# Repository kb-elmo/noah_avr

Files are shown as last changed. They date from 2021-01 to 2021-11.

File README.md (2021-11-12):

# Noah AVR

[][cc-by-nc-sa]
<a href="https://ko-fi.com/kb_elmo">kofibadge</a>

## This project is completed and will not get updated anymore.

### Atmega32u4 based drop-in replacement PCB for the Matrix Noah keyboard



---

[LCSC BOM](noah.csv)

[JLC CPL](noah-bottom-pos.csv)

[JST connectors for USB and RGB](https://www.digikey.de/product-detail/en/jst-sales-america-inc/SM04B-SRSS-TB-LF-SN/455-1804-1-ND/926875)

[SMD standoffs for daughterboard](https://www.digikey.de/en/products/detail/w%C3%BCrth-elektronik/9774030243R/5320628)

---




This work is licensed under a
[Creative Commons Attribution-NonCommercial-ShareAlike 4.0 International License][cc-by-nc-sa].

[][cc-by-nc-sa]

[cc-by-nc-sa]: http://creativecommons.org/licenses/by-nc-sa/4.0/
[cc-by-nc-sa-image]: https://licensebuttons.net/l/by-nc-sa/4.0/88x31.png
[cc-by-nc-sa-shield]: https://img.shields.io/badge/License-CC%20BY--NC--SA%204.0-lightgrey.svg

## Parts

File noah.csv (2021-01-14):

Comment | Designator | Footprint | LCSC
10uF | C1 | Capacitor_SMD:C_0805_2012Metric | C91245
0.1uF | C2,C3,C4,C5 | Capacitor_SMD:C_0805_2012Metric | C49678
1uF | C7 | Capacitor_SMD:C_0805_2012Metric | C28323
22pF | C8,C9 | Capacitor_SMD:C_0805_2012Metric | C1804
D_Small | D1,D2,D3,D4,D5,D6,D7,D8,D9,D10,D11,D12,D13,D14,D15,D17,D18,D19,D20,D21,D22,D23,D24,D25,D26,D27,D28,D29,D30,D32,D33,D35,D36 | custom_parts:D_SOT-23_ANK | C68978
D_Small | D16,D31,D34 | Diode_SMD:D_SOD-123 | C81598
Polyfuse_Small | F1 | Fuse:Fuse_1206_3216Metric | C163133
MountingHole | H1,H2,H3,H4 | MountingHole:MountingHole_3mm_Pad_Via
MX-NoLED | MX1 | MX_Only:MXOnly-2U-NoLED
MX-NoLED | MX19,MX32,MX66,MX68,MX70 | MX_Only:MXOnly-1.5U-NoLED
MX-NoLED | MX2,MX3,MX4,MX5,MX6,MX7,MX8,MX9,MX10,MX11,MX12,MX13,MX14,MX15,MX16,MX17,MX18,MX20,MX21,MX22,MX23,MX24,MX25,MX26,MX27,MX28,MX29,MX30,MX31,MX33,MX37,MX38,MX39,MX40,MX41,MX42,MX43,MX44,MX45,MX46,MX47,MX49,MX52,MX53,MX54,MX55,MX56,MX57,MX58,MX59,MX60,MX61,MX62,MX64,MX65,MX67,MX77,MX78,MX79 | MX_Only:MXOnly-1U-NoLED
MX-LED | MX34 | custom_parts:MXOnly-1.25U-flipped-LED
MX-NoLED | MX35 | custom_parts:MXOnly-ISO-ReversedStabilizers-NoLED
MX-LED | MX36 | MX_Only:MXOnly-1.75U
MX-NoLED | MX48 | MX_Only:MXOnly-2.25U-ReversedStabilizers-NoLED
MX-NoLED | MX51 | MX_Only:MXOnly-2.25U-NoLED
MX-NoLED | MX63 | MX_Only:MXOnly-1.75U-NoLED
MX-NoLED | MX69 | MX_Only:MXOnly-7U-ReversedStabilizers-NoLED
MX-NoLED | MX50,MX71,MX72,MX73,MX75,MX76 | MX_Only:MXOnly-1.25U-NoLED
MX-NoLED | MX74 | MX_Only:MXOnly-6.25U-ReversedStabilizers-NoLED
22 | R1,R2 | Resistor_SMD:R_0805_2012Metric | C17561
10k | R3,R5 | Resistor_SMD:R_0805_2012Metric | C17414
1k | R4 | Resistor_SMD:R_0805_2012Metric | C17513
SW_Push | RESET | random-keyboard-parts:SKQG-1155865 | C318884
ATmega32U4-AU | U1 | Package_QFP:TQFP-44_10x10mm_P0.8mm | C44854
SRV05-4 | U2 | Package_TO_SOT_SMD:SOT-23-6 | C85364
Conn_01x04 | USB1,RGB1 | Connector_JST:JST_SH_SM04B-SRSS-TB_1x04-1MP_P1.00mm_Horizontal
Crystal_GND24_Small | XTAL1 | Crystal:Crystal_SMD_3225-4Pin_3.2x2.5mm | C13738

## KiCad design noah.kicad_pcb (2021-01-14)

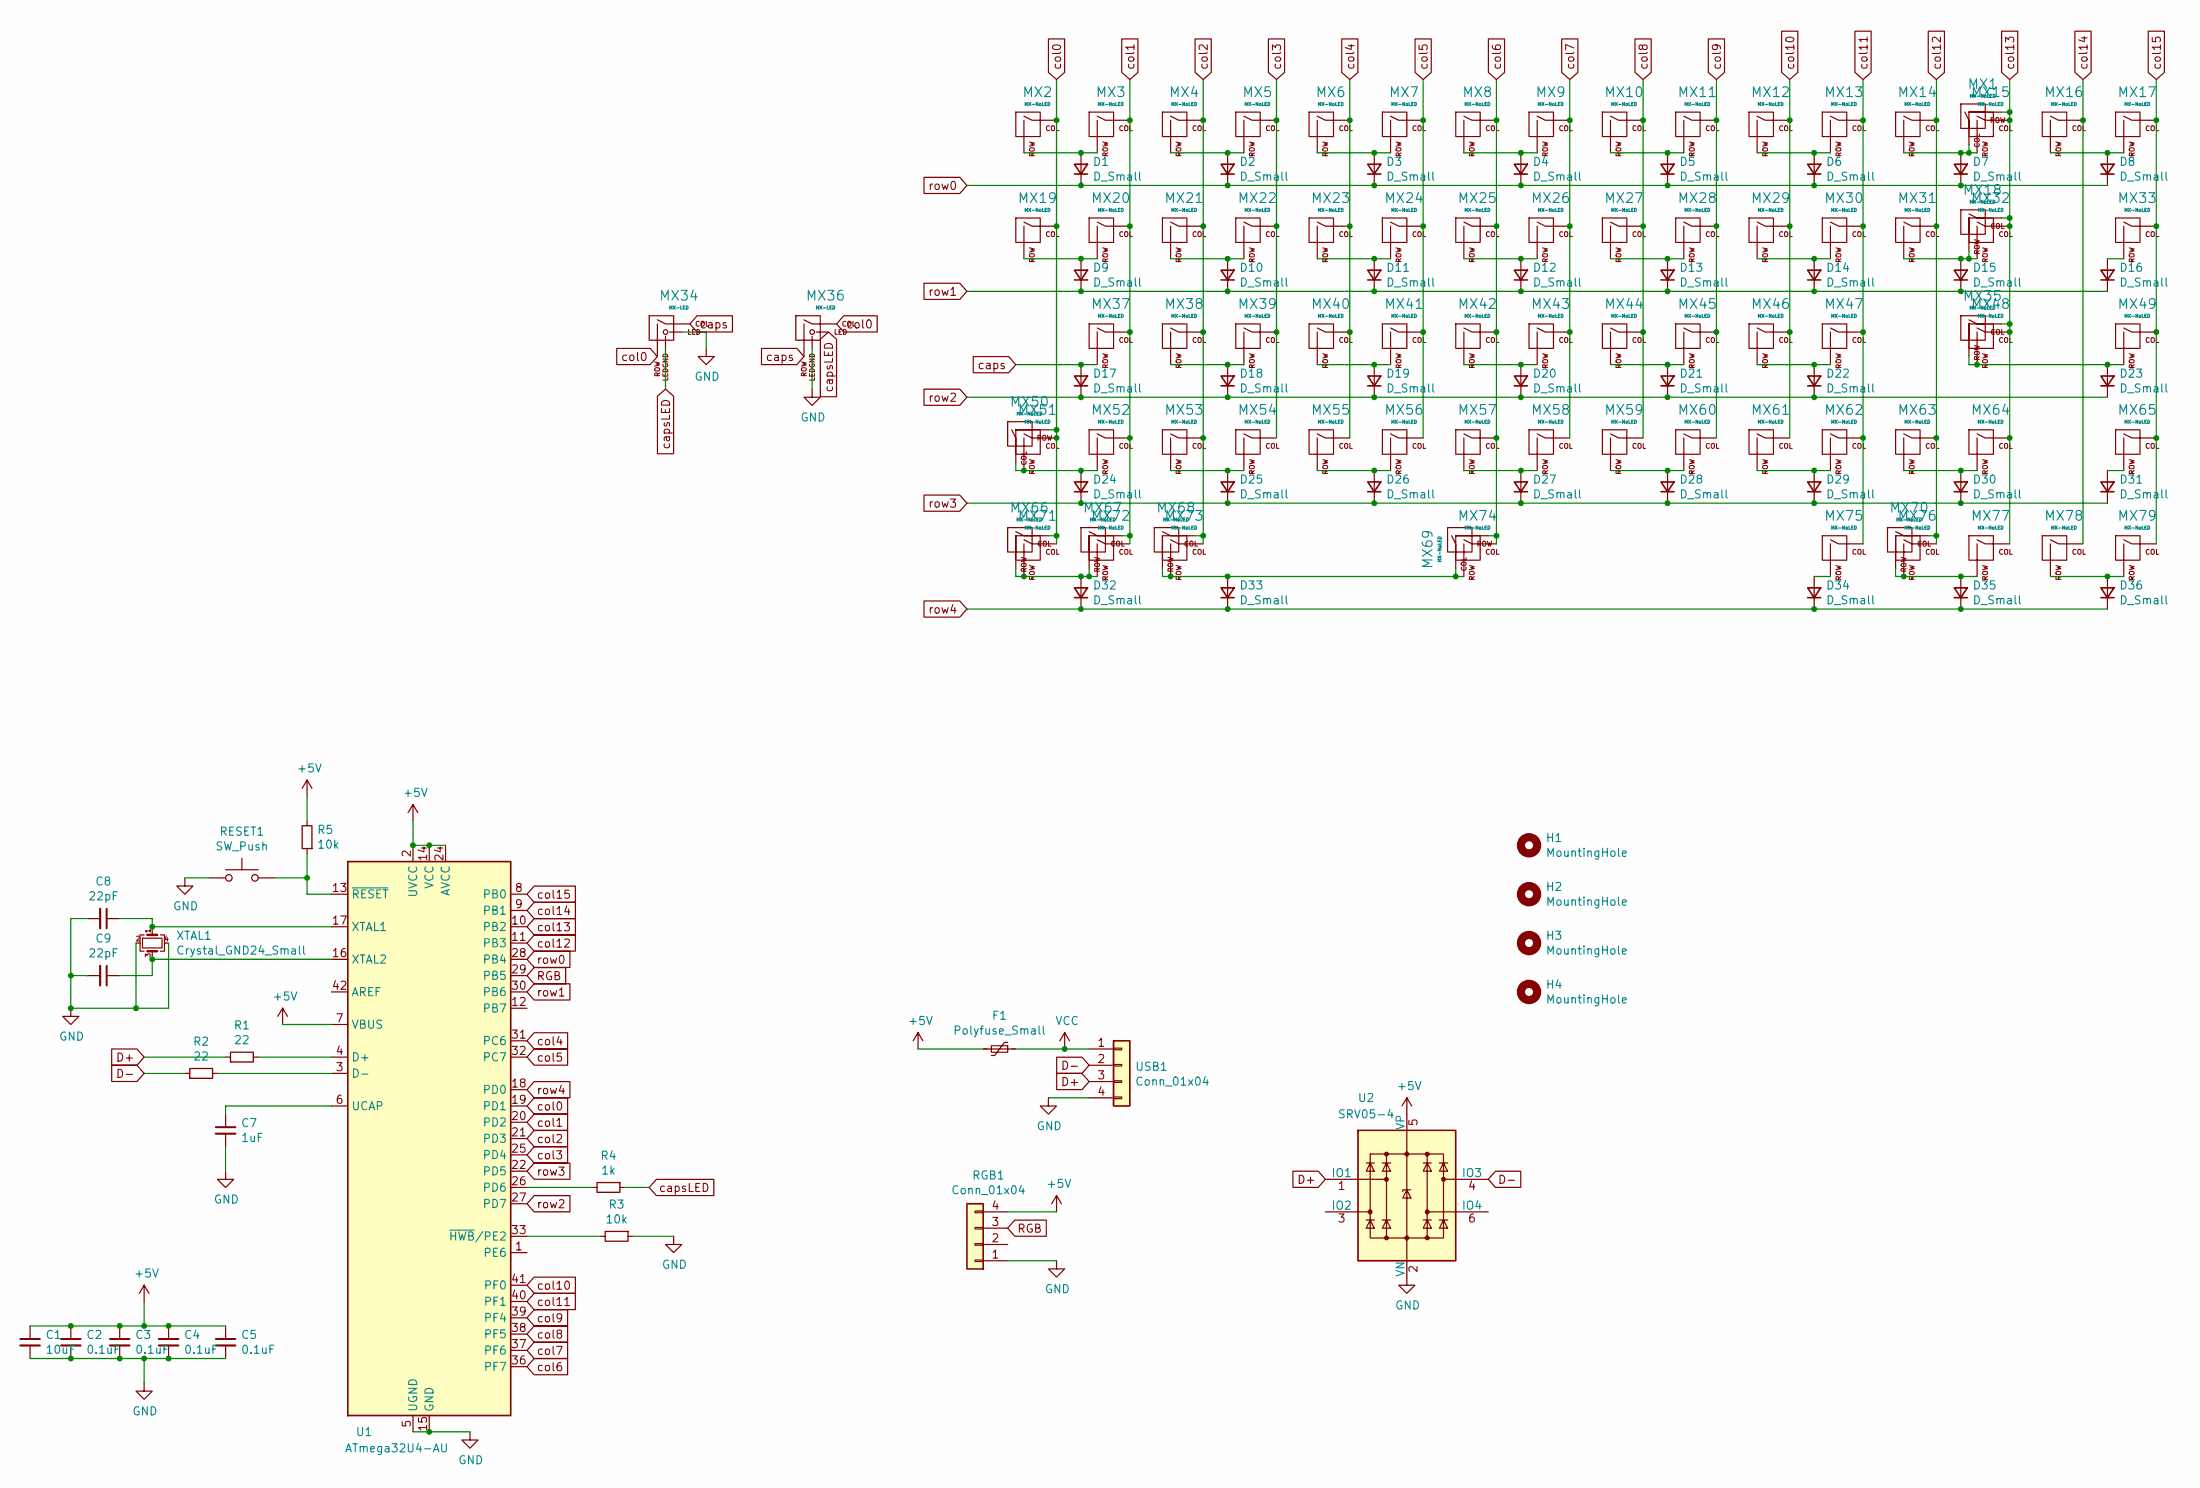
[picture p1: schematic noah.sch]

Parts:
C1: 10uF; C_0805_2012Metric; LCSC C91245
C2, C3, C4, C5: 0.1uF; C_0805_2012Metric; LCSC C49678
C7: 1uF; C_0805_2012Metric; LCSC C28323
C8, C9: 22pF; C_0805_2012Metric; LCSC C1804
D1, D2, D3, D4, D5, D6, D7, D8, D9, D10, D11, D12, D13, D14, D15, D17, D18, D19, D20, D21, D22, D23, D24, D25, D26, D27, D28, D29, D30, D32, D33, D35, D36: D_Small; D_SOT-23_ANK; LCSC C68978
D16, D31, D34: D_Small; D_SOD-123; LCSC C81598
F1: Polyfuse_Small; Fuse_1206_3216Metric; LCSC C163133
H1, H2, H3, H4: MountingHole; MountingHole_3mm_Pad_Via
MX1: MX-NoLED; MXOnly-2U-NoLED
MX2, MX3, MX4, MX5, MX6, MX7, MX8, MX9, MX10, MX11, MX12, MX13, MX14, MX15, MX16, MX17, MX18, MX20, MX21, MX22, MX23, MX24, MX25, MX26, MX27, MX28, MX29, MX30, MX31, MX33, MX37, MX38, MX39, MX40, MX41, MX42, MX43, MX44, MX45, MX46, MX47, MX49, MX52, MX53, MX54, MX55, MX56, MX57, MX58, MX59, MX60, MX61, MX62, MX64, MX65, MX67, MX77, MX78, MX79: MX-NoLED; MXOnly-1U-NoLED
MX19, MX32, MX66, MX68, MX70: MX-NoLED; MXOnly-1.5U-NoLED
MX34: MX-LED; MXOnly-1.25U-flipped-LED
MX35: MX-NoLED; MXOnly-ISO-ReversedStabilizers-NoLED
MX36: MX-LED; MXOnly-1.75U
MX48: MX-NoLED; MXOnly-2.25U-ReversedStabilizers-NoLED
MX50, MX71, MX72, MX73, MX75, MX76: MX-NoLED; MXOnly-1.25U-NoLED
MX51: MX-NoLED; MXOnly-2.25U-NoLED
MX63: MX-NoLED; MXOnly-1.75U-NoLED
MX69: MX-NoLED; MXOnly-7U-ReversedStabilizers-NoLED
MX74: MX-NoLED; MXOnly-6.25U-ReversedStabilizers-NoLED
R1, R2: 22; R_0805_2012Metric; LCSC C17561
R3, R5: 10k; R_0805_2012Metric; LCSC C17414
R4: 1k; R_0805_2012Metric; LCSC C17513
RESET1: SW_Push; SKQG-1155865; LCSC C318884
RGB1: Conn_01x04; JST_SH_SM04B-SRSS-TB_1x04-1MP_P1.00mm_Horizontal
U1: ATmega32U4-AU; TQFP-44_10x10mm_P0.8mm; LCSC C44854
U2: SRV05-4; SOT-23-6; LCSC C85364
USB1: Conn_01x04; JST_SH_SM04B-SRSS-TB_1x04-1MP_P1.00mm_Horizontal
XTAL1: Crystal_GND24_Small; Crystal_SMD_3225-4Pin_3.2x2.5mm; LCSC C13738

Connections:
+5V: C1.1, C2.1, C3.1, C4.1, C5.1, F1.2, R5.2, RGB1.4, U1.2 (UVCC), U1.7 (VBUS), U1.14 (VCC), U1.24 (AVCC), U1.34 (VCC), U1.44 (AVCC), U2.5 (VP)
D+: R1.1, U2.1 (IO1), USB1.3
D-: R2.1, U2.4 (IO3), USB1.2
GND: C1.2, C2.2, C3.2, C4.2, C5.2, C7.2, C8.2, C9.2, MX34.3 (LED), MX36.4 (LEDGND), R3.1, RESET1.1, RGB1.1, U1.5 (UGND), U1.15 (GND), U1.23 (GND), U1.35 (GND), U1.43 (GND), U2.2 (VN), USB1.4, XTAL1.2, XTAL1.4; also elsewhere on the board
unnamed: C7.1, U1.6 (UCAP)
unnamed: C8.1, U1.17 (XTAL1), XTAL1.1
unnamed: C9.1, U1.16 (XTAL2), XTAL1.3
unnamed: D1.2 (A), MX2.2 (ROW), MX3.2 (ROW)
unnamed: D2.2 (A), MX4.2 (ROW), MX5.2 (ROW)
unnamed: D3.2 (A), MX6.2 (ROW), MX7.2 (ROW)
unnamed: D4.2 (A), MX8.2 (ROW), MX9.2 (ROW)
unnamed: D5.2 (A), MX10.2 (ROW), MX11.2 (ROW)
unnamed: D6.2 (A), MX12.2 (ROW), MX13.2 (ROW)
unnamed: D7.2 (A), MX1.1 (COL), MX14.2 (ROW), MX15.2 (ROW)
unnamed: D8.2 (A), MX16.2 (ROW), MX17.2 (ROW)
unnamed: D9.2 (A), MX19.2 (ROW), MX20.2 (ROW)
unnamed: D10.2 (A), MX21.2 (ROW), MX22.2 (ROW)
unnamed: D11.2 (A), MX23.2 (ROW), MX24.2 (ROW)
unnamed: D12.2 (A), MX25.2 (ROW), MX26.2 (ROW)
unnamed: D13.2 (A), MX27.2 (ROW), MX28.2 (ROW)
unnamed: D14.2 (A), MX29.2 (ROW), MX30.2 (ROW)
unnamed: D15.2 (A), MX18.2 (ROW), MX31.2 (ROW), MX32.2 (ROW)
unnamed: D16.2 (A), MX33.2 (ROW)
unnamed: D18.2 (A), MX38.2 (ROW), MX39.2 (ROW)
unnamed: D19.2 (A), MX40.2 (ROW), MX41.2 (ROW)
unnamed: D20.2 (A), MX42.2 (ROW), MX43.2 (ROW)
unnamed: D21.2 (A), MX44.2 (ROW), MX45.2 (ROW)
unnamed: D22.2 (A), MX46.2 (ROW), MX47.2 (ROW)
unnamed: D23.2 (A), MX35.2 (ROW), MX48.2 (ROW), MX49.2 (ROW)
unnamed: D24.2 (A), MX50.1 (COL), MX51.2 (ROW), MX52.2 (ROW)
unnamed: D25.2 (A), MX53.2 (ROW), MX54.2 (ROW)
unnamed: D26.2 (A), MX55.2 (ROW), MX56.2 (ROW)
unnamed: D27.2 (A), MX57.2 (ROW), MX58.2 (ROW)
unnamed: D28.2 (A), MX59.2 (ROW), MX60.2 (ROW)
unnamed: D29.2 (A), MX61.2 (ROW), MX62.2 (ROW)
unnamed: D30.2 (A), MX63.2 (ROW), MX64.2 (ROW)
unnamed: D31.2 (A), MX65.2 (ROW)
unnamed: D32.2 (A), MX66.2 (ROW), MX67.2 (ROW), MX71.2 (ROW), MX72.2 (ROW)
unnamed: D33.2 (A), MX68.2 (ROW), MX69.1 (COL), MX73.2 (ROW), MX74.2 (ROW)
unnamed: D34.2 (A), MX75.2 (ROW)
unnamed: D35.2 (A), MX70.2 (ROW), MX76.2 (ROW), MX77.2 (ROW)
unnamed: D36.2 (A), MX78.2 (ROW), MX79.2 (ROW)
unnamed: R1.2, U1.4 (D+)
unnamed: R2.2, U1.3 (D-)
unnamed: R3.2, U1.33 (~HWB~/PE2)
unnamed: R4.2, U1.26 (PD6)
unnamed 46: R5.1, RESET1.2, U1.13 (~RESET); also elsewhere on the board
RGB: RGB1.3, U1.29 (PB5)
VCC: F1.1, USB1.1
caps: D17.2 (A), MX34.1 (COL), MX36.2 (ROW), MX37.2 (ROW)
capsLED: MX34.4 (LEDGND), MX36.3 (LED), R4.1
col0: MX2.1 (COL), MX19.1 (COL), MX34.2 (ROW), MX36.1 (COL), MX50.2 (ROW), MX51.1 (COL), MX66.1 (COL), MX71.1 (COL), U1.19 (PD1)
col1: MX3.1 (COL), MX20.1 (COL), MX37.1 (COL), MX52.1 (COL), MX67.1 (COL), MX72.1 (COL), U1.20 (PD2)
col2: MX4.1 (COL), MX21.1 (COL), MX38.1 (COL), MX53.1 (COL), MX68.1 (COL), MX73.1 (COL), U1.21 (PD3)
col3: MX5.1 (COL), MX22.1 (COL), MX39.1 (COL), MX54.1 (COL), U1.25 (PD4)
col4: MX6.1 (COL), MX23.1 (COL), MX40.1 (COL), MX55.1 (COL), U1.31 (PC6)
col5: MX7.1 (COL), MX24.1 (COL), MX41.1 (COL), MX56.1 (COL), U1.32 (PC7)
col6: MX8.1 (COL), MX25.1 (COL), MX42.1 (COL), MX57.1 (COL), MX69.2 (ROW), MX74.1 (COL), U1.36 (PF7)
col7: MX9.1 (COL), MX26.1 (COL), MX43.1 (COL), MX58.1 (COL), U1.37 (PF6)
col8: MX10.1 (COL), MX27.1 (COL), MX44.1 (COL), MX59.1 (COL), U1.38 (PF5)
col9: MX11.1 (COL), MX28.1 (COL), MX45.1 (COL), MX60.1 (COL), U1.39 (PF4)
col10: MX12.1 (COL), MX29.1 (COL), MX46.1 (COL), MX61.1 (COL), U1.41 (PF0)
col11: MX13.1 (COL), MX30.1 (COL), MX47.1 (COL), MX62.1 (COL), MX75.1 (COL), U1.40 (PF1)
col12: MX14.1 (COL), MX31.1 (COL), MX63.1 (COL), MX70.1 (COL), MX76.1 (COL), U1.11 (PB3)
col13: MX1.2 (ROW), MX15.1 (COL), MX18.1 (COL), MX32.1 (COL), MX35.1 (COL), MX48.1 (COL), MX64.1 (COL), MX77.1 (COL), U1.10 (PB2)
col14: MX16.1 (COL), MX78.1 (COL), U1.9 (PB1)
col15: MX17.1 (COL), MX33.1 (COL), MX49.1 (COL), MX65.1 (COL), MX79.1 (COL), U1.8 (PB0)
row0: D1.1 (K), D2.1 (K), D3.1 (K), D4.1 (K), D5.1 (K), D6.1 (K), D7.1 (K), D8.1 (K), U1.28 (PB4)
row1: D9.1 (K), D10.1 (K), D11.1 (K), D12.1 (K), D13.1 (K), D14.1 (K), D15.1 (K), D16.1 (K), U1.30 (PB6)
row2: D17.1 (K), D18.1 (K), D19.1 (K), D20.1 (K), D21.1 (K), D22.1 (K), D23.1 (K), U1.27 (PD7)
row3: D24.1 (K), D25.1 (K), D26.1 (K), D27.1 (K), D28.1 (K), D29.1 (K), D30.1 (K), D31.1 (K), U1.22 (PD5)
row4: D32.1 (K), D33.1 (K), D34.1 (K), D35.1 (K), D36.1 (K), U1.18 (PD0)

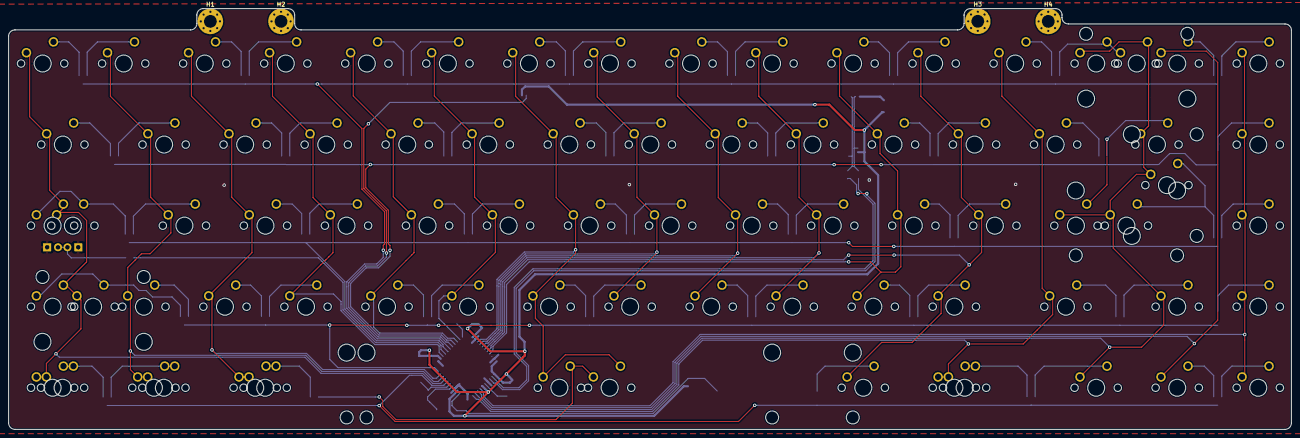
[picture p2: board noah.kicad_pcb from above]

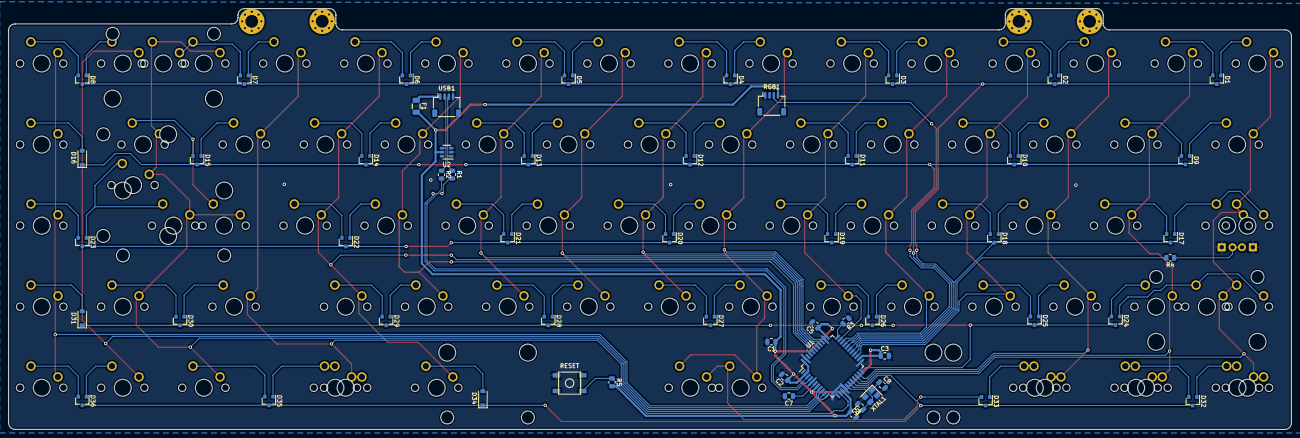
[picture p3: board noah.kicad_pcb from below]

Board: 2 copper layers, 301.5 x 98.9 mm, 139 parts (56 on the bottom side), 72 nets.

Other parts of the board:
RESET: SW_Push; SKQG-1155865

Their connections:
GND: RESET.1; also elsewhere on the board
unnamed 46: RESET.2; also elsewhere on the board

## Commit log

2021-01-02 add LCSC BOM and placing files
    [noah.csv, noah.sch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]
2021-01-02 fix BOM
    [noah.csv, noah.sch]
2021-01-03 update BOM
    [noah.csv, noah.kicad_pcb, noah.sch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]
2021-01-14 fix DB plug wire orientation
    [noah.kicad_pcb, noah.sch]
2021-01-14 update gerbers
    [noah.csv, noah.kicad_pcb]

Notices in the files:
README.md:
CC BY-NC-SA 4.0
